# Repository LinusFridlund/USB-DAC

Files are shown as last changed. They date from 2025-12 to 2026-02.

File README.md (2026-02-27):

# USB-DAC
A high quality USB audio DAC.
This project is intended as a test for my larger music streamer project that implements a DAC chip together with a STM32 microconroller.
It accepts a music stream over USB, outputs the analog audio over balanced XLR connections and has an OLED display to show stream info. 

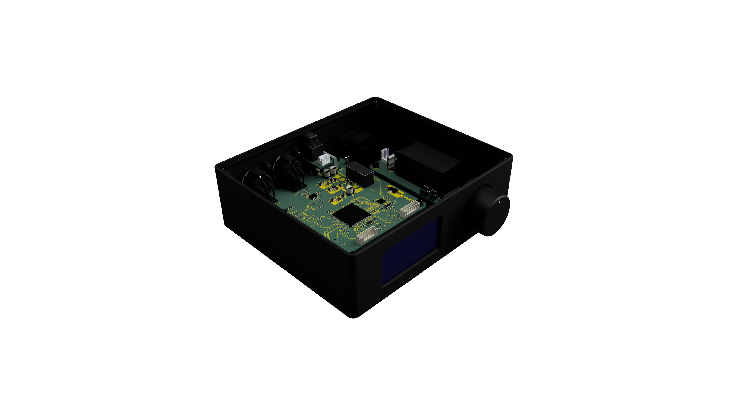
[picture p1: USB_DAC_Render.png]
Image of render

Image of a render of the PCBs together with  the case.

## Hardware
The main part of the hardware is the custom developed PCB housing the STM32, DAC chip and its accompanying components
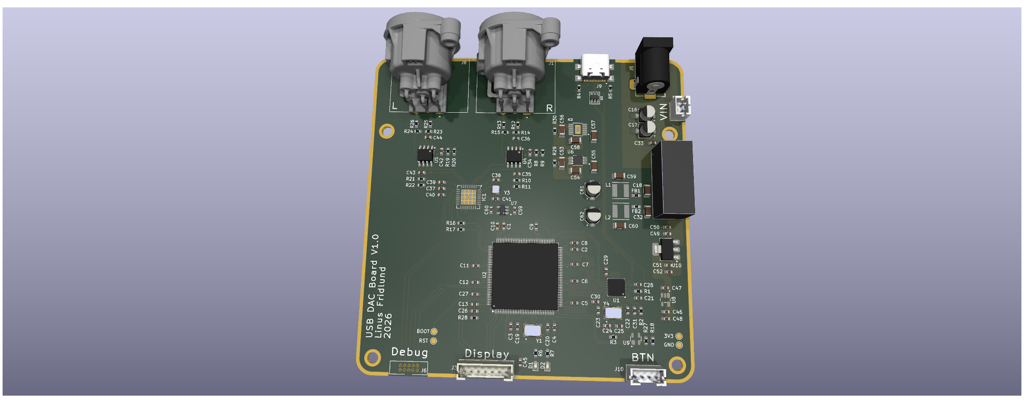
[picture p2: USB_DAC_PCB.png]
Image of early PCB design


### Microcontroller
A STM32H7 series microcontroller was chosen for its high performance and support for interfaces such as USB HS and SAI (Serial Audio Interface) which are used in the project. In addition I also have previous experience with STM32 based systems. Cost and power consumption were no priorities here since I am only building one unit and it is powered by an external power supply.

### DAC Chip
The DAC chip used is the ESS ES9039Q2M. It is a chip that is widely used in many other DACs meaning other designs are easy to reference. The datasheet includes important info about recommended output stages, power supply schemes and all the neccesary software details. For these reasons, along with its availability online made it a good choice.

### Power supply
A small PSU board with a Mean Well 12V supply feeds into a +-12V switching power supply on the main DAC board. The outptus then get filtered through a ferrite bead and a pi filter before being regulated to +-9V and 3.3V for the analog section. The incoming 12V also gets regulated down with less filtering to 5 and 3.3V for the digital components.

### PCB Design considerations
Extra attention had to be given to a couple of key areas in the PCB design in order to achieve a good result.
#### Stackup
A 4 layer stackup is used with the top and bottom being signal layers and the inner layers being ground and power in order to provide easy routing and better signal integrity.
#### Digital signal integrity
The USB signals and the ULPI signals between the USB PHY and the STM32 both operate at high frequencies and thus require proper impedance and length matching to ensure their functionality. 
#### 

## Software

The software development will start when the hardware is finished and ordered. So far I have only played around a bit and gotten a rough idea of how it will be structured.

## Current status
Currently the hardware design is finished and the PCBs have arrived. Currently the boards are being assembled, then the software development begins!

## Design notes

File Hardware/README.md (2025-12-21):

# Hardware

## PCB

## Enclosure

## Other parts

### Display
The display used is a 2.42 inch 128 x 64 px oled display from waveshare.
Link: https://www.waveshare.com/2.42inch-oled-module.htm

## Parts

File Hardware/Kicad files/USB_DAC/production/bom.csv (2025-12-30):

Designator | Footprint | Quantity | Value | LCSC Part #
C1, C2 | 0603 | 2 | 2u2
C10, C11, C12, C13, C18, C26, C27, C28, C29, C3, C30, C31, C32, C33, C4, C45, C5, C6, C7, C8, C9 | 0603 | 21 | 100n
C14, C15, C16, C17 | CP_Elec_4x4.5 | 4 | 100u
C19, C20, C21, C22, C23, C24, C25 | 0603 | 7 | C
C34, C35, C42, C43 | 0603 | 4 | 510p
C36, C44 | 0603 | 2 | 10p
C37, C38, C39, C40, C41 | 0603 | 5 | 1u
D1, D2 | 0603 | 2 | LED
IC1 | QFN-32-1EP_7x7mm_P0.65mm_EP4.7x4.7mm | 1 | ES9039Q2M
IC2 | SOP65P490X110-13N | 1 | LT3094EDD_PBF
J1, J8 | NEUTRIK_NC3MAH | 2 | NC3MAH
J10 | JST_B4B-PH-K-S | 1 | B4B-PH-K-S
J2 | RCJ-2221 | 1 | RCJ-2234
J3 | JST_PH_B7B-PH-K_1x07_P2.00mm_Vertical | 1 | B7B-PH-K-S
J5 | BarrelJack_Horizontal | 1 | Jack-DC
J6 | 2X10_BOXHEADER | 1 | Conn_ARM_JTAG_SWD_10
J7 | JST_B2B-PH-K-S | 1 | B2B-PH-K-S
J9 | GCT_USB4110GFA | 1 | USB4110GFA
PS1 | CONV_TMR_3-1223E | 1 | TMR_3-1223E
R1 | 0603 | 1 | 820
R10, R11, R19, R20, R21, R22, R8, R9 | 0603 | 8 | 3k6
R12, R13, R25, R26 | 0603 | 4 | 140
R14, R15, R23, R24 | 0603 | 4 | 4k7
R16, R17 | 0603 | 2 | 47k
R18 | 0603 | 1 | 100
R2 | 0603 | 1 | 12k 1%
R3 | 0603 | 1 | 1M
R4, R5 | 0603 | 2 | 5K1
R6, R7 | 0603 | 2 | 1k
U1 | QFN-32-1EP_5x5mm_P0.5mm_EP3.45x3.45mm | 1 | USB3300-EZK
U2 | LQFP-144_20x20mm_P0.5mm | 1 | STM32H723ZGTx
U3 | SOT-457 | 1 | IP4234CZ6
U4, U5 | SOIC-8_3.9x4.9mm_P1.27mm | 2 | OPA1612AxD
U6 | SOP50P490X110-11N | 1 | LT3042IMSE_PBF
U7 | SOT95P280X145-5N | 1 | TPS7A2033PDBVR
Y3 | Oscillator_SMD_Abracon_ASDMB-4Pin_2.5x2.0mm | 1 | NSC5083D

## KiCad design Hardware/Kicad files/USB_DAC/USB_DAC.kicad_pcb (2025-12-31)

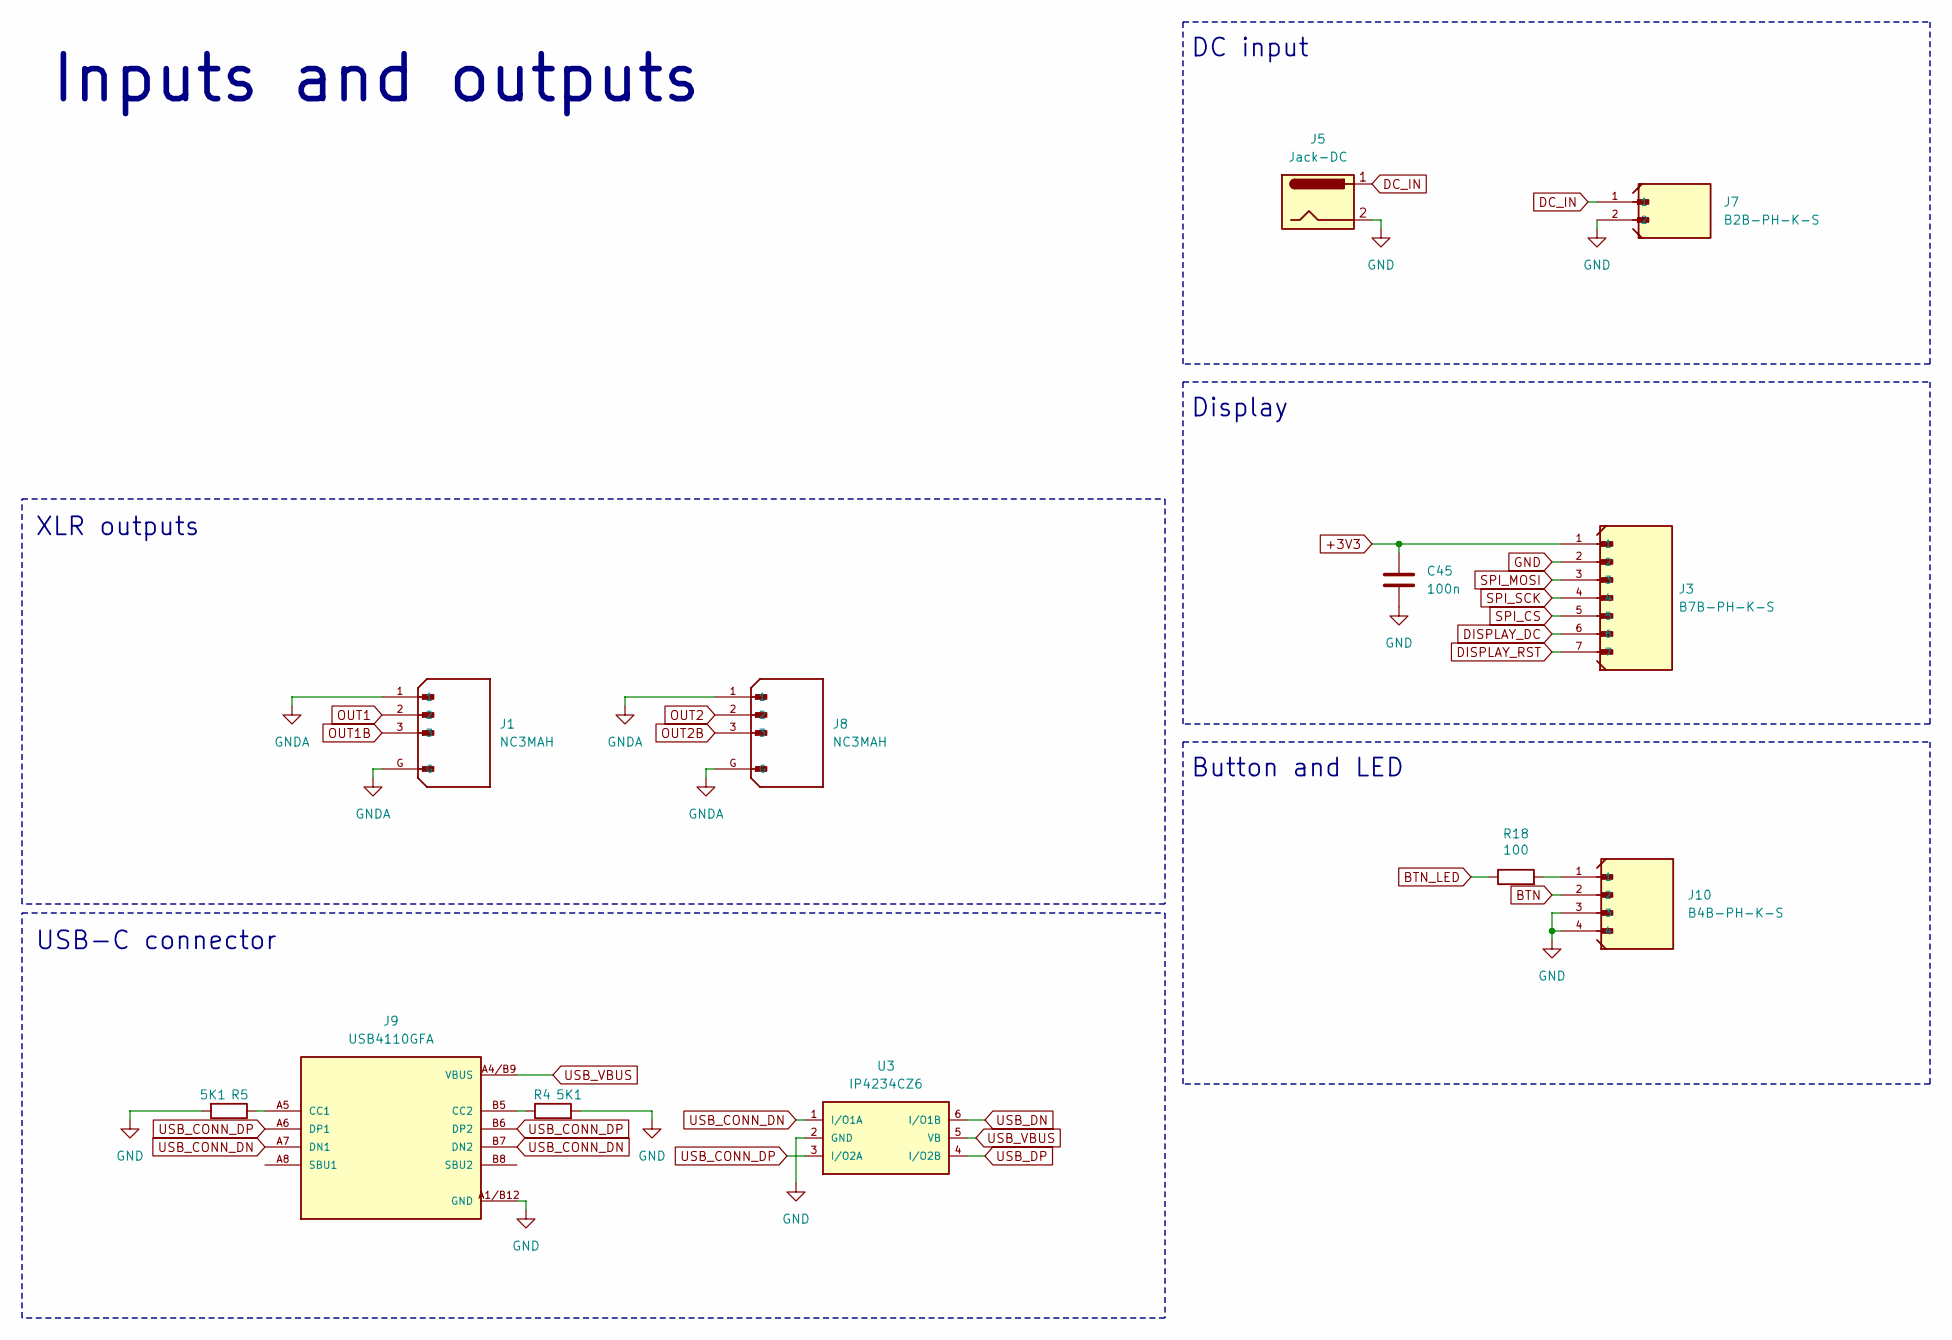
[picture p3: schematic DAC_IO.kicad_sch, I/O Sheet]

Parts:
C45: 100n; C_0603_1608Metric
J1, J8: NC3MAH; NEUTRIK_NC3MAH; PARTREV 30.03.09
J3: B7B-PH-K-S; JST_PH_B7B-PH-K_1x07_P2.00mm_Vertical
J5: Jack-DC; BarrelJack_Horizontal
J7: B2B-PH-K-S; JST_B2B-PH-K-S
J9: USB4110GFA; GCT_USB4110GFA
J10: B4B-PH-K-S; JST_B4B-PH-K-S
R4, R5: 5K1; R_0603_1608Metric
R18: 100; R_0603_1608Metric
U3: IP4234CZ6; SOT-457

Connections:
+3V3: C45.1, J3.1; also elsewhere on the board
BTN: J10.2; also elsewhere on the board
BTN_LED: R18.1; also elsewhere on the board
DC_IN: J5.1, J7.1; also elsewhere on the board
DISPLAY_DC: J3.6; also elsewhere on the board
DISPLAY_RST: J3.7; also elsewhere on the board
GNDA: J1.1, J1.G, J8.1, J8.G; also elsewhere on the board
unnamed: J9.A5 (CC1), R5.1
unnamed: J9.B5 (CC2), R4.1
unnamed: J10.1, R18.2
OUT1: J1.2; also elsewhere on the board
OUT1B: J1.3; also elsewhere on the board
OUT2: J8.2; also elsewhere on the board
OUT2B: J8.3; also elsewhere on the board
SPI_CS: J3.5; also elsewhere on the board
SPI_MOSI: J3.3; also elsewhere on the board
SPI_SCK: J3.4; also elsewhere on the board
USB_CONN_DN: J9.A7 (DN1), J9.B7 (DN2), U3.1 (I/O1A)
USB_CONN_DP: J9.A6 (DP1), J9.B6 (DP2), U3.3 (I/O2A)
USB_DN: U3.6 (I/O1B); also elsewhere on the board
USB_DP: U3.4 (I/O2B); also elsewhere on the board
USB_VBUS: J9.A4/B9 (VBUS), J9.B4/A9 (VBUS), U3.5 (VB); also elsewhere on the board

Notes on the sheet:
Button and LED
XLR outputs
Inputs and outputs
Display
DC input
USB-C connector

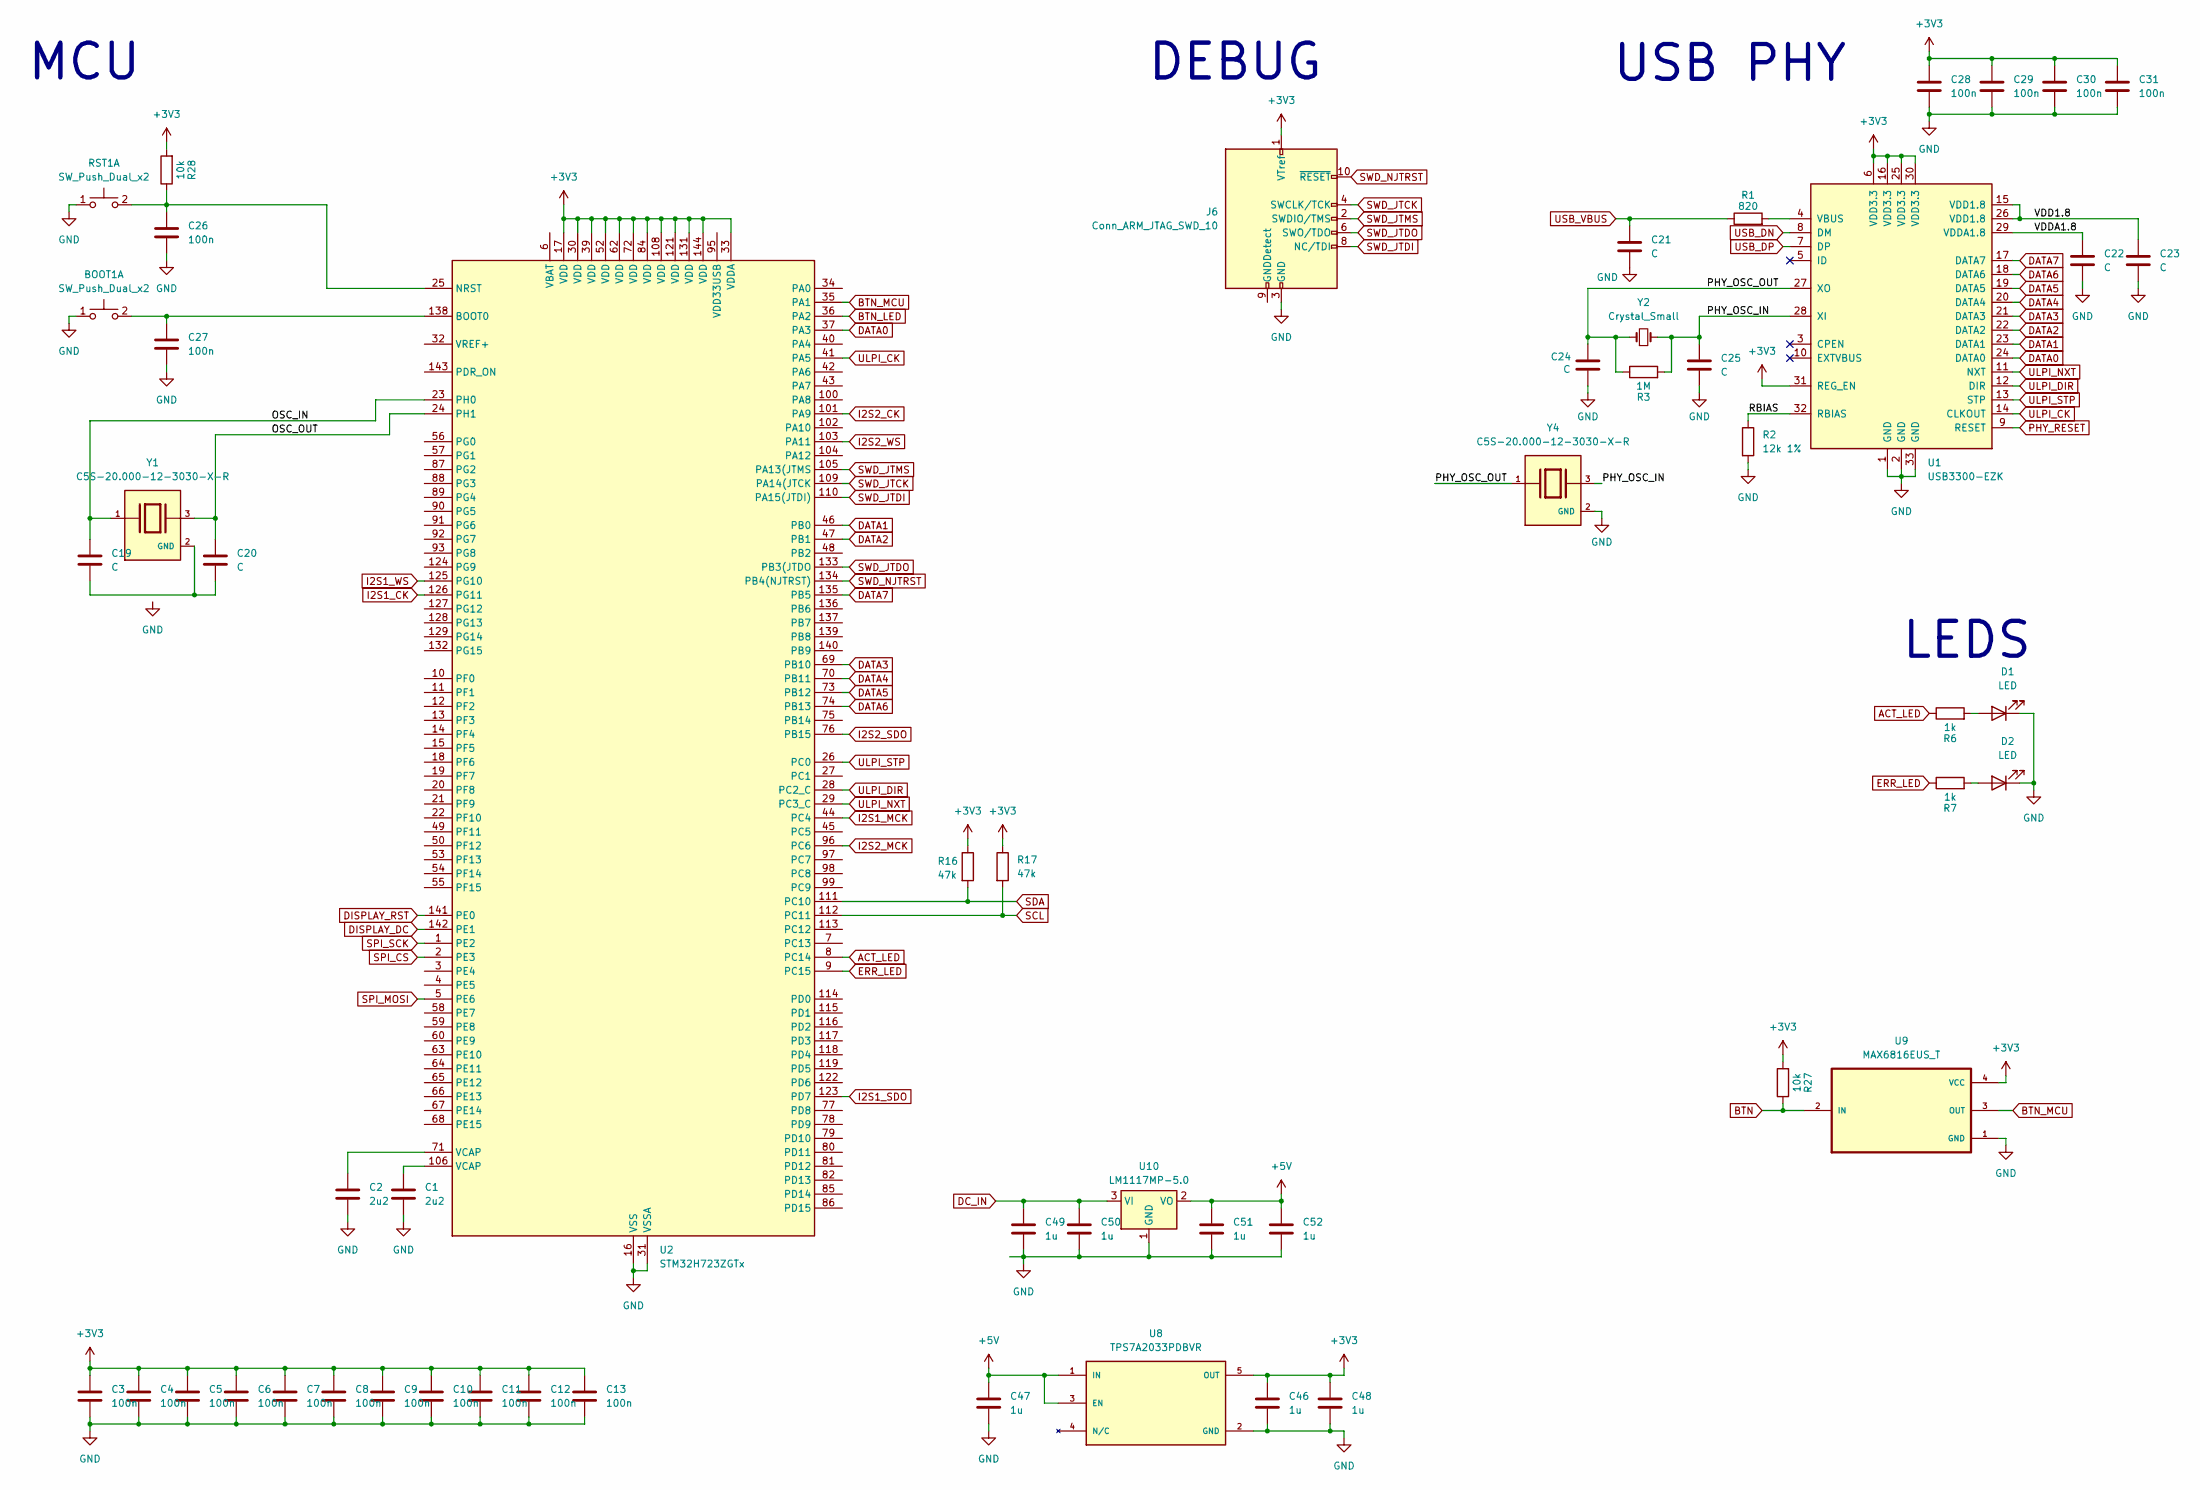
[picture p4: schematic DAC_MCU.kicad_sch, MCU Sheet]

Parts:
BOOT1: SW_Push_Dual_x2
C1, C2: 2u2; C_0603_1608Metric
C3, C4, C5, C6, C7, C8, C9, C10, C11, C12, C13, C26, C27, C28, C29, C30, C31: 100n; C_0603_1608Metric
C19, C20, C21, C22, C23, C24, C25: C; C_0603_1608Metric
C46, C47, C48, C49, C50, C51, C52: 1u; C_0603_1608Metric
D1, D2: LED; LED_0603_1608Metric
J6: Conn_ARM_JTAG_SWD_10; 2X10_BOXHEADER
R1: 820; R_0603_1608Metric
R2: 12k 1%; R_0603_1608Metric
R3: 1M; R_0603_1608Metric
R6, R7: 1k; R_0603_1608Metric
R16, R17: 47k; R_0603_1608Metric
R27, R28: 10k; R_0603_1608Metric
RST1: SW_Push_Dual_x2
U1: USB3300-EZK; QFN-32-1EP_5x5mm_P0.5mm_EP3.45x3.45mm
U2: STM32H723ZGTx; LQFP-144_20x20mm_P0.5mm
U8: TPS7A2033PDBVR; SOT95P280X145-5N; PARTREV H
U9: MAX6816EUS_T; SOT192P237X122-4N
U10: LM1117MP-5.0; SOT-223-3_TabPin2
Y1, Y4: C5S-20.000-12-3030-X-R; XTAL_C5S-20.000-12-3030-X-R; PARTREV N/A
Y2: Crystal_Small

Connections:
+3V3: C3.1, C4.1, C5.1, C6.1, C7.1, C8.1, C9.1, C10.1, C11.1, C12.1, C13.1, C28.1, C29.1, C30.1, C31.1, C46.1, C48.1, J6.1 (VTref), R16.1, R17.1, R27.2, R28.2, U1.6 (VDD3.3), U1.16 (VDD3.3), U1.25 (VDD3.3), U1.30 (VDD3.3), U1.31 (REG_EN), U2.17 (VDD), U2.30 (VDD), U2.33 (VDDA), U2.39 (VDD), U2.52 (VDD), U2.62 (VDD), U2.72 (VDD), U2.84 (VDD), U2.108 (VDD), U2.121 (VDD), U2.131 (VDD), U2.144 (VDD), U8.5 (OUT), U9.4 (VCC); also elsewhere on the board
+5V: C47.1, C51.1, C52.1, U8.1 (IN), U8.3 (EN), U10.2 (VO)
/MCU/OSC_IN: C19.1, U2.23 (PH0), Y1.1
/MCU/OSC_OUT: C20.1, U2.24 (PH1), Y1.3
/MCU/PHY_OSC_IN: C25.1, R3.2, U1.28 (XI), Y2.2, Y4.3
/MCU/PHY_OSC_OUT: C24.1, R3.1, U1.27 (XO), Y2.1, Y4.1
/MCU/RBIAS: R2.1, U1.32 (RBIAS)
/MCU/VDD1.8: C23.1, U1.15 (VDD1.8), U1.26 (VDD1.8)
/MCU/VDDA1.8: C22.1, U1.29 (VDDA1.8)
ACT_LED: R6.1, U2.8 (PC14)
BTN: R27.1, U9.2 (IN); also elsewhere on the board
BTN_LED: U2.36 (PA2); also elsewhere on the board
BTN_MCU: U2.35 (PA1), U9.3 (OUT)
DATA0: U1.24 (DATA0), U2.37 (PA3)
DATA1: U1.23 (DATA1), U2.46 (PB0)
DATA2: U1.22 (DATA2), U2.47 (PB1)
DATA3: U1.21 (DATA3), U2.69 (PB10)
DATA4: U1.20 (DATA4), U2.70 (PB11)
DATA5: U1.19 (DATA5), U2.73 (PB12)
DATA6: U1.18 (DATA6), U2.74 (PB13)
DATA7: U1.17 (DATA7), U2.135 (PB5)
DC_IN: C49.1, C50.1, U10.3 (VI); also elsewhere on the board
DISPLAY_DC: U2.142 (PE1); also elsewhere on the board
DISPLAY_RST: U2.141 (PE0); also elsewhere on the board
ERR_LED: R7.1, U2.9 (PC15)
I2S1_CK: U2.126 (PG11)
I2S1_MCK: U2.44 (PC4)
I2S1_SDO: U2.123 (PD7)
I2S1_WS: U2.125 (PG10)
I2S2_CK: U2.101 (PA9); also elsewhere on the board
I2S2_MCK: U2.96 (PC6)
I2S2_SDO: U2.76 (PB15); also elsewhere on the board
I2S2_WS: U2.103 (PA11); also elsewhere on the board
unnamed 44: BOOT1.2 (D), C27.1, U2.138 (BOOT0); also elsewhere on the board
unnamed: C1.1, U2.106 (VCAP)
unnamed: C2.1, U2.71 (VCAP)
unnamed: D1.2 (A), R6.2
unnamed: D2.2 (A), R7.2
unnamed 59: C26.1, R28.1, RST1.2 (D), U2.25 (NRST); also elsewhere on the board
unnamed: R1.2, U1.4 (VBUS)
PHY_RESET: U1.9 (RESET)
SCL: R17.2, U2.112 (PC11); also elsewhere on the board
SDA: R16.2, U2.111 (PC10); also elsewhere on the board
SPI_CS: U2.2 (PE3); also elsewhere on the board
SPI_MOSI: U2.5 (PE6); also elsewhere on the board
SPI_SCK: U2.1 (PE2); also elsewhere on the board
SWD_JTCK: J6.4 (SWCLK/TCK), U2.109 (PA14(JTCK)
SWD_JTDI: J6.8 (NC/TDI), U2.110 (PA15(JTDI))
SWD_JTDO: J6.6 (SWO/TDO), U2.133 (PB3(JTDO)
SWD_JTMS: J6.2 (SWDIO/TMS), U2.105 (PA13(JTMS)
SWD_NJTRST: J6.10 (~RESET), U2.134 (PB4(NJTRST))
ULPI_CK: U1.14 (CLKOUT), U2.41 (PA5)
ULPI_DIR: U1.12 (DIR), U2.28 (PC2_C)
ULPI_NXT: U1.11 (NXT), U2.29 (PC3_C)
ULPI_STP: U1.13 (STP), U2.26 (PC0)
USB_DN: U1.8 (DM); also elsewhere on the board
USB_DP: U1.7 (DP); also elsewhere on the board
USB_VBUS: C21.1, R1.1; also elsewhere on the board

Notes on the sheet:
LEDS
USB PHY
MCU
DEBUG

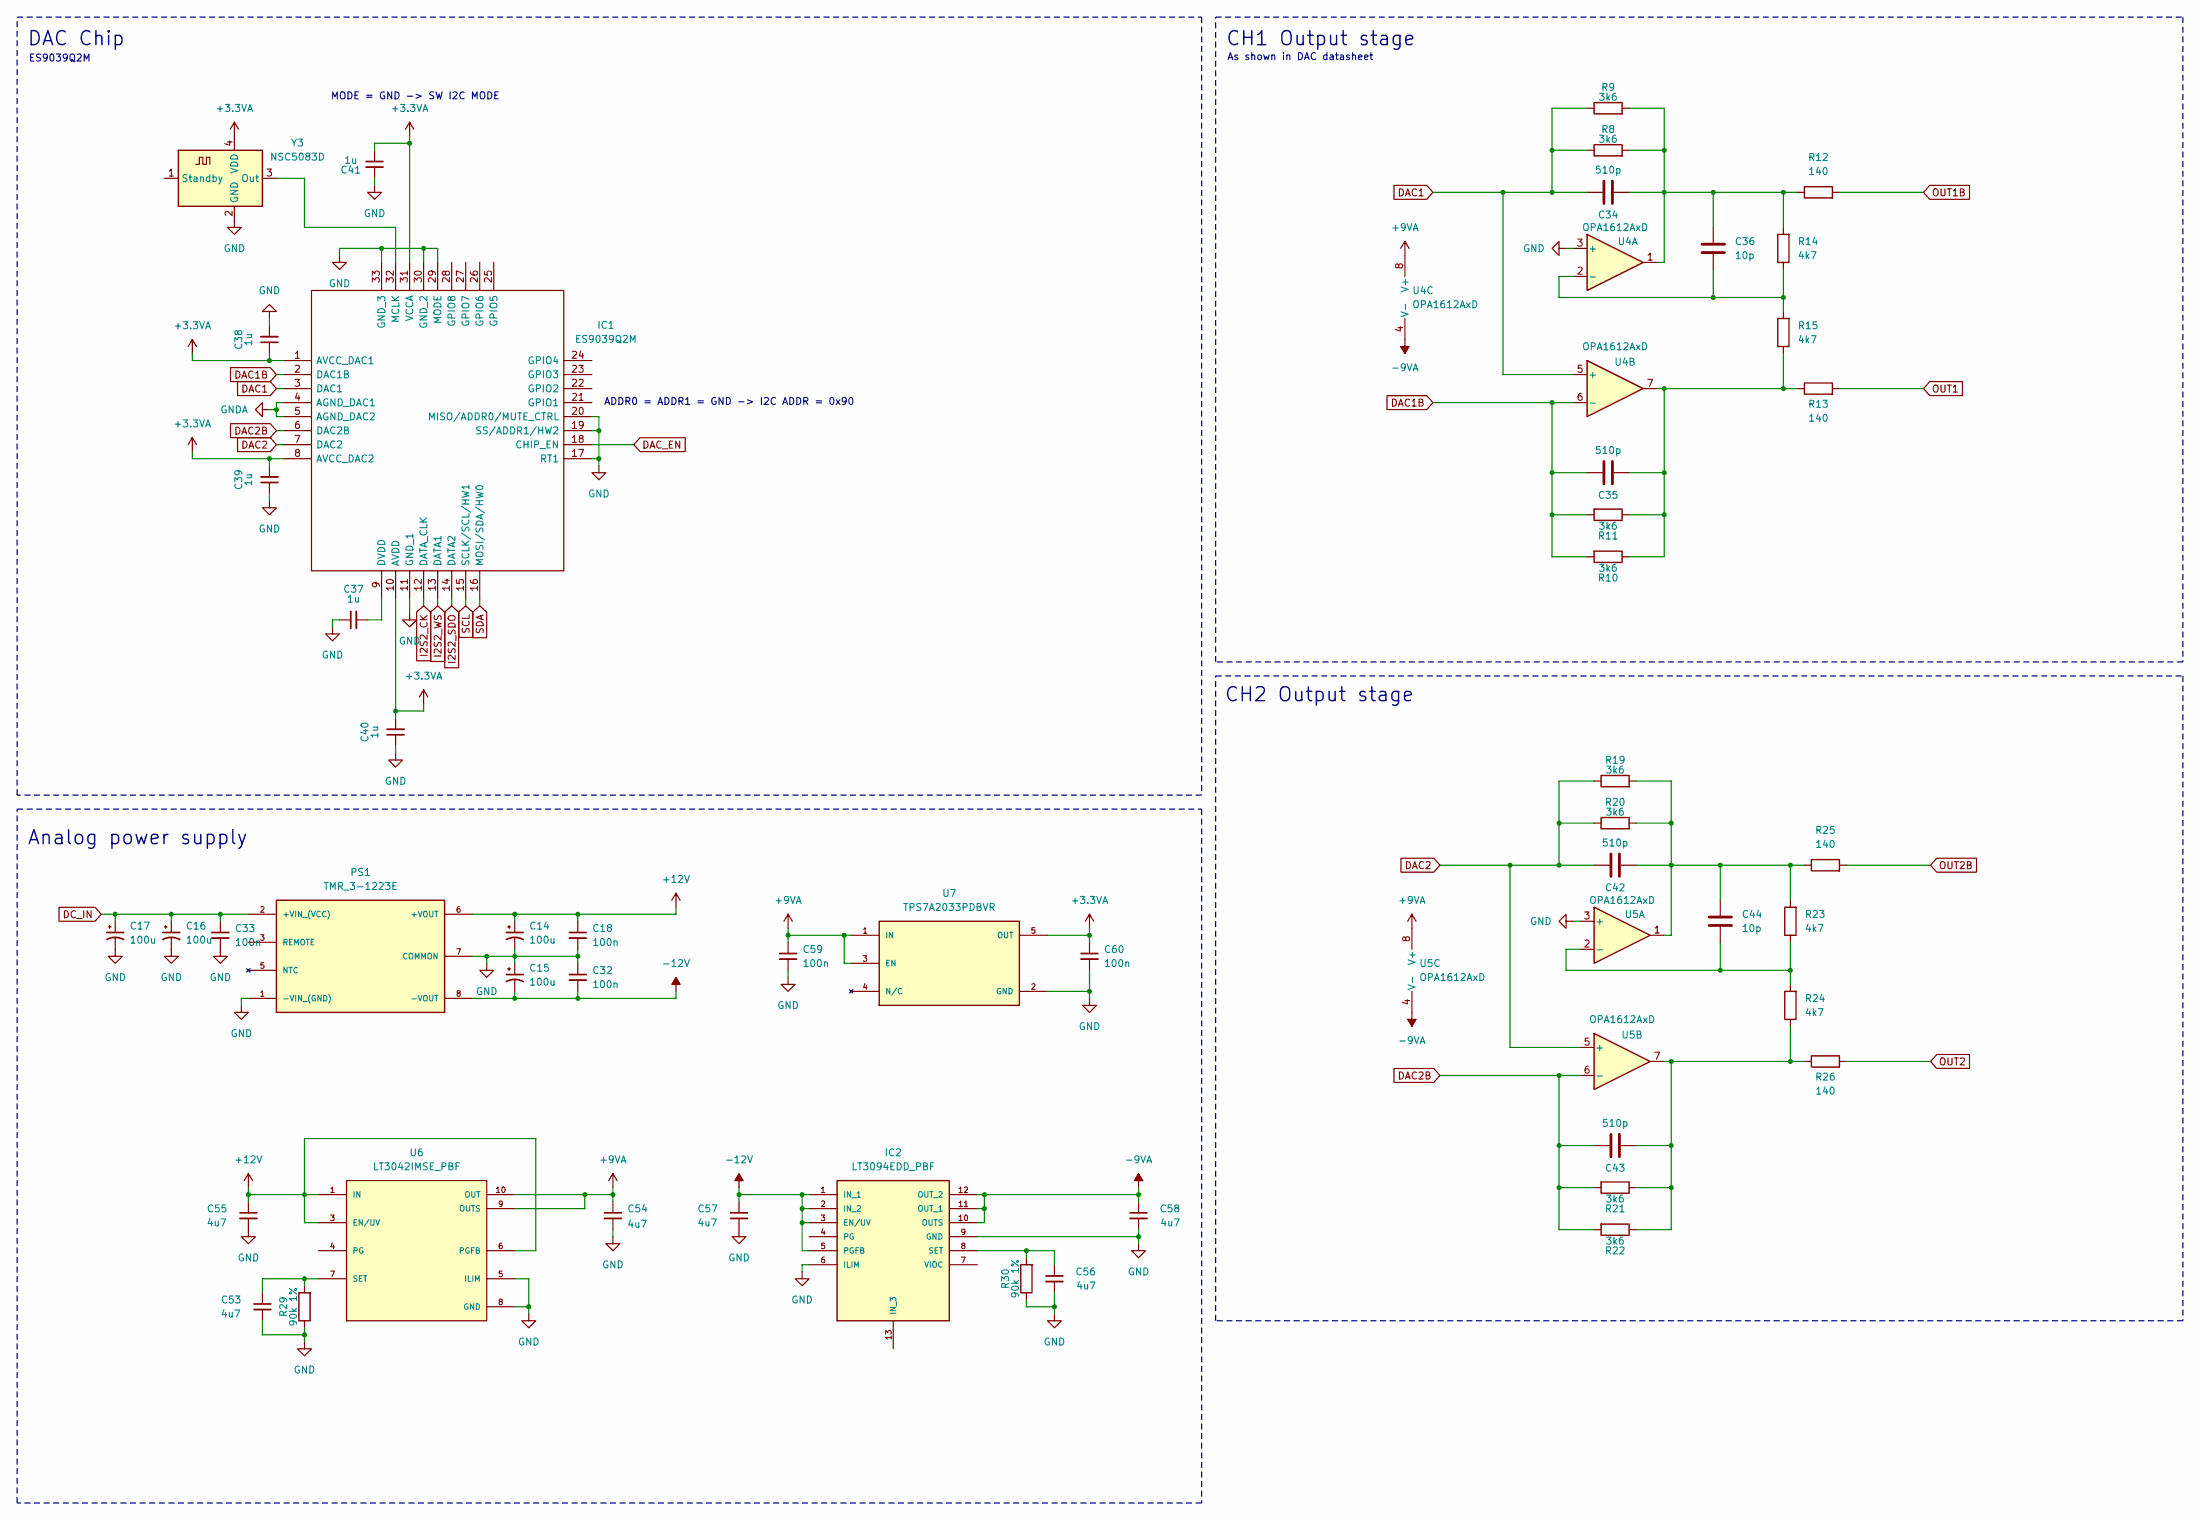
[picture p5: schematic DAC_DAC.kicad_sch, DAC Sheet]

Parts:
C14, C15, C16, C17: 100u; CP_Elec_4x4.5
C18, C32, C33, C59, C60: 100n; C_0603_1608Metric
C34, C35, C42, C43: 510p; C_0603_1608Metric
C36, C44: 10p; C_0603_1608Metric
C37, C38, C39, C40, C41: 1u; C_0603_1608Metric
C53, C54, C55, C56, C57, C58: 4u7; C_1206_3216Metric
IC1: ES9039Q2M; QFN-32-1EP_7x7mm_P0.65mm_EP4.7x4.7mm; Mouser Part Number 460-ES9039Q2M
IC2: LT3094EDD_PBF; SOP65P490X110-13N; MOUSER_PART_NUMBER 584-LT3094EDD#PBF
PS1: TMR_3-1223E; CONV_TMR_3-1223E; PARTREV March 9, 2021
R8, R9, R10, R11, R19, R20, R21, R22: 3k6; R_0603_1608Metric
R12, R13, R25, R26: 140; R_0603_1608Metric
R14, R15, R23, R24: 4k7; R_0603_1608Metric
R29, R30: 90k 1%; R_0603_1608Metric
U4, U5: OPA1612AxD; SOIC-8_3.9x4.9mm_P1.27mm
U6: LT3042IMSE_PBF; SOP50P490X110-11N; PARTREV B
U7: TPS7A2033PDBVR; SOT95P280X145-5N; PARTREV H
Y3: NSC5083D; Oscillator_SMD_Abracon_ASDMB-4Pin_2.5x2.0mm

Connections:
+3.3VA: C38.1, C39.2, C40.2, C41.1, C60.1, IC1.1 (AVCC_DAC1), IC1.8 (AVCC_DAC2), IC1.10 (AVDD), IC1.31 (VCCA), U7.5 (OUT), Y3.4 (VDD)
+9VA: C54.1, C59.1, U4.8 (V+), U5.8 (V+), U6.9 (OUTS), U6.10 (OUT), U7.1 (IN), U7.3 (EN)
+12V: C14.1, C18.1, C55.1, PS1.6 (+VOUT), U6.1 (IN), U6.2 (IN), U6.3 (EN/UV), U6.6 (PGFB)
-9VA: C58.1, IC2.10 (OUTS), IC2.11 (OUT_1), IC2.12 (OUT_2), U4.4 (V-), U5.4 (V-)
-12V: C15.2, C32.2, C57.1, IC2.1 (IN_1), IC2.2 (IN_2), IC2.3 (EN/UV), IC2.5 (PGFB), PS1.8 (-VOUT)
DAC1: C34.1, IC1.3 (DAC1), R8.1, R9.1, U4.5 (+)
DAC1B: C35.1, IC1.2 (DAC1B), R10.2, R11.2, U4.6 (-)
DAC2: C42.1, IC1.7 (DAC2), R19.1, R20.1, U5.5 (+)
DAC2B: C43.1, IC1.6 (DAC2B), R21.2, R22.2, U5.6 (-)
DAC_EN: IC1.18 (CHIP_EN)
DC_IN: C16.1, C17.1, C33.1, PS1.2 (+VIN_(VCC)); also elsewhere on the board
GNDA: IC1.4 (AGND_DAC1), IC1.5 (AGND_DAC2); also elsewhere on the board
I2S2_CK: IC1.12 (DATA_CLK); also elsewhere on the board
I2S2_SDO: IC1.14 (DATA2); also elsewhere on the board
I2S2_WS: IC1.13 (DATA1); also elsewhere on the board
unnamed: C34.2, C36.1, R8.2, R9.2, R12.1, R14.2, U4.1
unnamed: C35.2, R10.1, R11.1, R13.1, R15.1, U4.7
unnamed: C42.2, C44.1, R19.2, R20.2, R23.2, R25.1, U5.1
unnamed: C43.2, R21.1, R22.1, R24.1, R26.1, U5.7
unnamed: C37.2, IC1.9 (DVDD)
unnamed: IC1.32 (MCLK), Y3.3 (Out)
unnamed: C56.1, IC2.8 (SET), R30.2
unnamed: C36.2, R14.1, R15.2, U4.2 (-)
unnamed: C44.2, R23.1, R24.2, U5.2 (-)
unnamed: C53.1, R29.2, U6.7 (SET)
OUT1: R13.2; also elsewhere on the board
OUT1B: R12.2; also elsewhere on the board
OUT2: R26.2; also elsewhere on the board
OUT2B: R25.2; also elsewhere on the board
SCL: IC1.15 (SCLK/SCL/HW1); also elsewhere on the board
SDA: IC1.16 (MOSI/SDA/HW0); also elsewhere on the board

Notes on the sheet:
ES9039Q2M
As shown in DAC datasheet
Analog power supply
CH1 Output stage
CH2 Output stage
DAC Chip
ADDR0 = ADDR1 = GND -> I2C ADDR = 0x90
MODE = GND -> SW I2C MODE

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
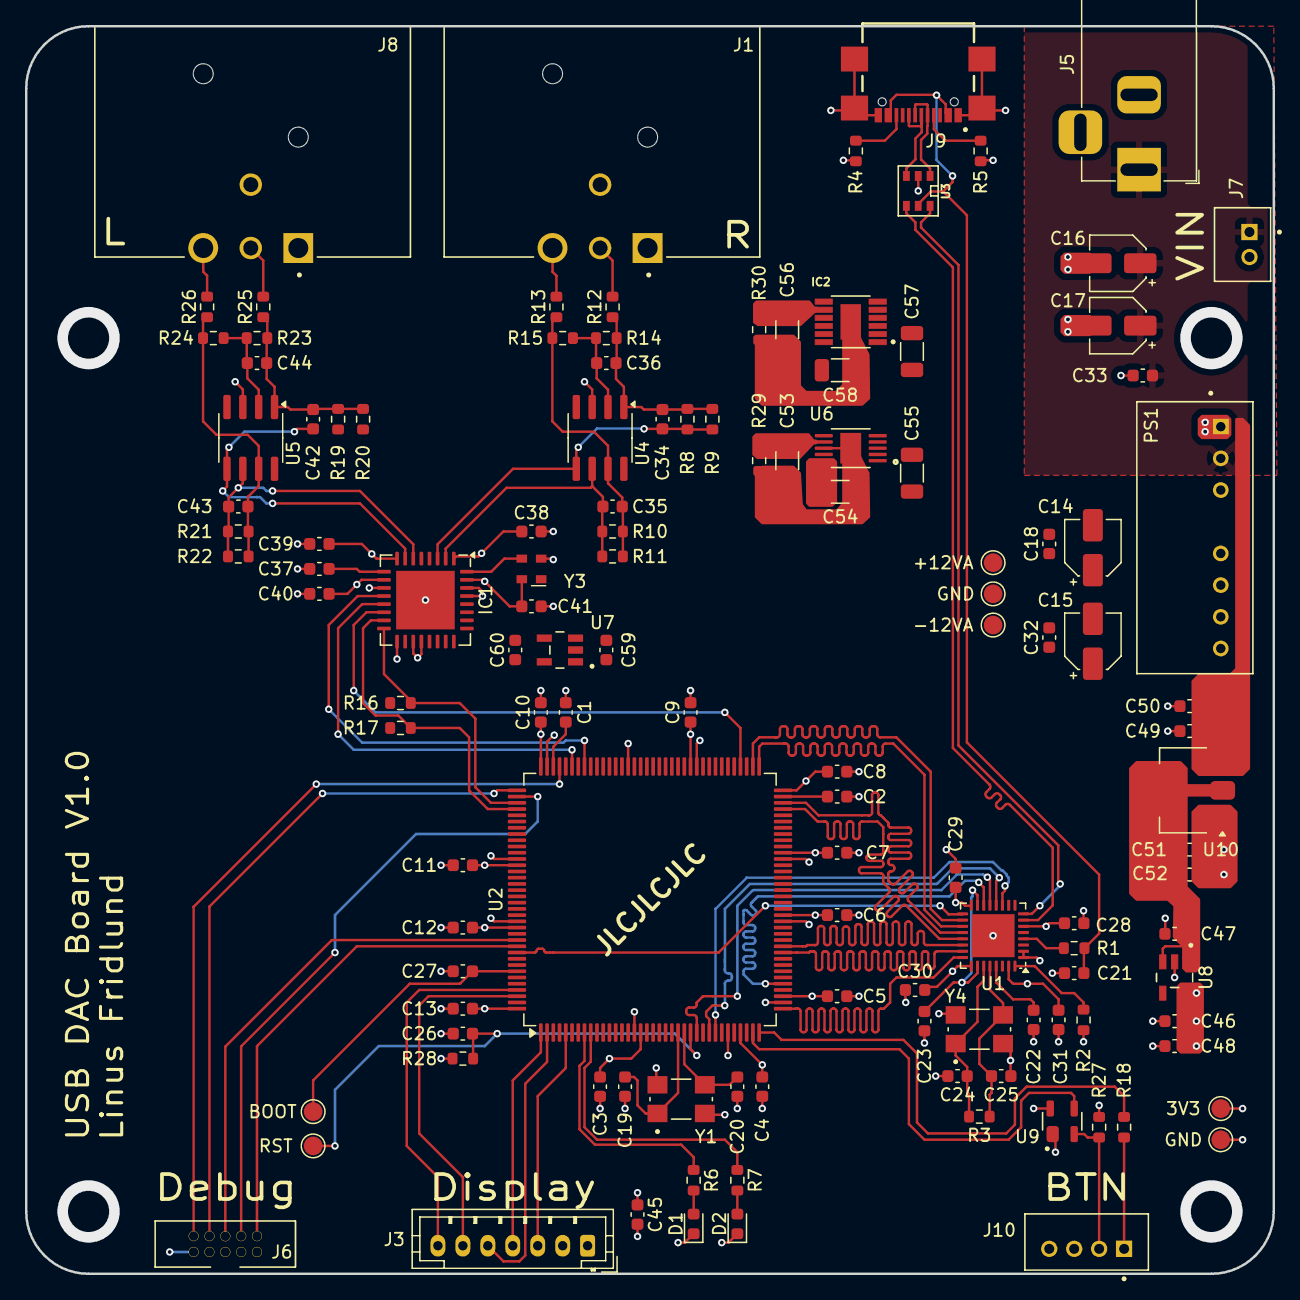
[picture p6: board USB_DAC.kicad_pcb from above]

Board: 4 copper layers, 100.0 x 100.0 mm, 123 parts (0 on the bottom side), 82 nets.

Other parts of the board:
3V3: TestPoint_Pad_D1.5mm
+12VA: TestPoint_Pad_D1.5mm
-12VA: TestPoint_Pad_D1.5mm
BOOT: TestPoint_Pad_D1.5mm
GND: TestPoint_Pad_D1.5mm
GND#2: TestPoint_Pad_D1.5mm
RST: TestPoint_Pad_D1.5mm

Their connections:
+3V3: 3V3.1; also elsewhere on the board
unnamed 44: BOOT.1; also elsewhere on the board
unnamed 59: RST.1; also elsewhere on the board

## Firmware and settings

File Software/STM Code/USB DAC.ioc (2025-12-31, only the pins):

Mcu.UserName=STM32H723ZGTx
PA11.Signal=I2S2_WS
PA3.Signal=USB_OTG_HS_ULPI_D0
PA5.Signal=USB_OTG_HS_ULPI_CK
PA9.Signal=I2S2_CK
PB0.Signal=USB_OTG_HS_ULPI_D1
PB1.Signal=USB_OTG_HS_ULPI_D2
PB10.Signal=USB_OTG_HS_ULPI_D3
PB11.Signal=USB_OTG_HS_ULPI_D4
PB12.Signal=USB_OTG_HS_ULPI_D5
PB13.Signal=USB_OTG_HS_ULPI_D6
PB15.Signal=I2S2_SDO
PB5.Signal=USB_OTG_HS_ULPI_D7
PC0.Signal=USB_OTG_HS_ULPI_STP
PC10.Signal=I2C5_SDA
PC11.Signal=I2C5_SCL
PC2_C.Signal=USB_OTG_HS_ULPI_DIR
PC3_C.Signal=USB_OTG_HS_ULPI_NXT
PE12.Signal=SAI4_SCK_B
PE2.Signal=SPI4_SCK
PE6.Signal=SPI4_MOSI
PG10.Signal=SAI4_SD_B
PG9.Signal=SAI4_FS_B
PH0-OSC_IN.Signal=RCC_OSC_IN
PH1-OSC_OUT.Signal=RCC_OSC_OUT

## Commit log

2025-12-20 Added Kicad files
    [DAC_DAC.kicad_sch, DAC_IO.kicad_sch, DAC_MCU.kicad_sch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]
2025-12-22 added STM code files and modified PCB
    [DAC_IO.kicad_sch, DAC_MCU.kicad_sch, USB_DAC.kicad_pcb]
2025-12-28 Add PCB image
2025-12-30 Updated PCB and schematics
    [DAC_DAC.kicad_sch, DAC_IO.kicad_sch, DAC_MCU.kicad_sch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]
